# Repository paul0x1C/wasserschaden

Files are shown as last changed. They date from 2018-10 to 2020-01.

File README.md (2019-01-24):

# wasserschaden
Project to control solenoid valves over mqtt, check each nodes status in a webpage and via Grafana. 
It allows you to set a location for each node that connects for the first time for easier maintenance.
Nodes equipped with a temperature sensor also send temperature information via mqtt.
To prevent two solenoid valves opening simultaniously, a house enters "locked state". Before opening a solenoid valve,
it checks the lockstate of its house and will only open if the house is in unlocked state.
We log every opening and closing of a valve in order to be able to generate a csv log file, to prove reliability.

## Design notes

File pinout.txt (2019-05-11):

D1 GPIO5: valve (HIGH == OPEN) (20K PULLDOWN)
D2 GIPO4: info LED (HIGH == ON)
D6 GIPO12: sense (green screw terminal) (330R PULLUP)
D7 GIPO13: one wire temperature sensor (4K7 PULLUP)

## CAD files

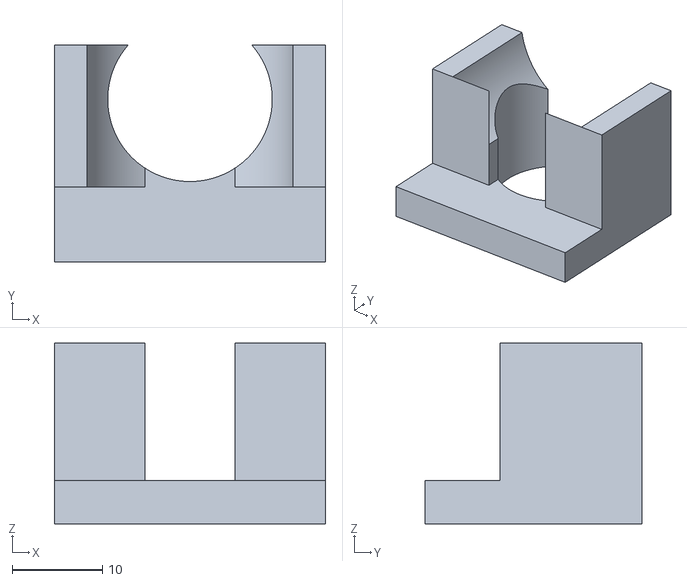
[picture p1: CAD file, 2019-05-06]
3D_models/valve.stl
30.0 x 24.0 x 20.0

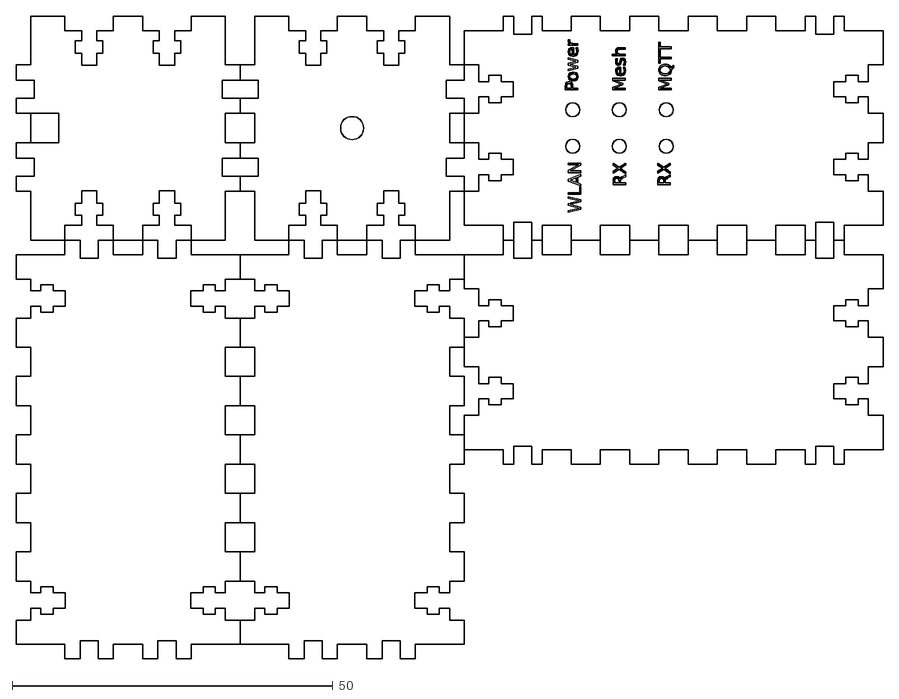
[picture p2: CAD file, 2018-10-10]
bridge_case/caseplans.dxf
135.1 x 100.2

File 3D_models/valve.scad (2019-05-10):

$fn = 300;

out_thread_h = 10.84;
out_thread_r = 10.33;
middle_h = 42.64;
middle_r = 9.1;
in_thrad_h = 10.21;
in_thread_r = 13.07;
overall_h = 65.88;
bent_middle_h = overall_h - (out_thread_h+middle_h+in_thrad_h);

rot_mid_h = 18.81;
rot_cube_h = 9.96;

module valve(){
     cylinder(r = out_thread_r, h=out_thread_h);
     translate([0,0,out_thread_h]){ //above outter thread
             translate([0,0,21.78]){//middle of the valve
                rotate([90,0,0]){
                  translate([0,0,-middle_r]){
                      cylinder(d=23.1,h=rot_mid_h);
                    translate([0,0,rot_mid_h]){
                        translate([0,0,rot_cube_h/2])cube([34,34,rot_cube_h], center=true);
                         cube([10,34,12], center = true);
                    }
                    }
              }
         }
         cylinder(r=middle_r, h=middle_h);
         translate([0,0,middle_h]){
             cylinder(r1=middle_r, r2=out_thread_r, h= bent_middle_h);
             translate([0,0,bent_middle_h])
                 cylinder(r=out_thread_r, h=out_thread_h);
         }
     }
}
translate([0,0,-out_thread_h])valve();
c_x = 30;
c_y = 24;
c_z = 20;
difference(){
    translate([-c_x/2,-c_y+6,0])
   color([1,0,0],0.8) cube([c_x,c_y,c_z]);
    translate([0,0,-out_thread_h])
    valve();
    
    
}

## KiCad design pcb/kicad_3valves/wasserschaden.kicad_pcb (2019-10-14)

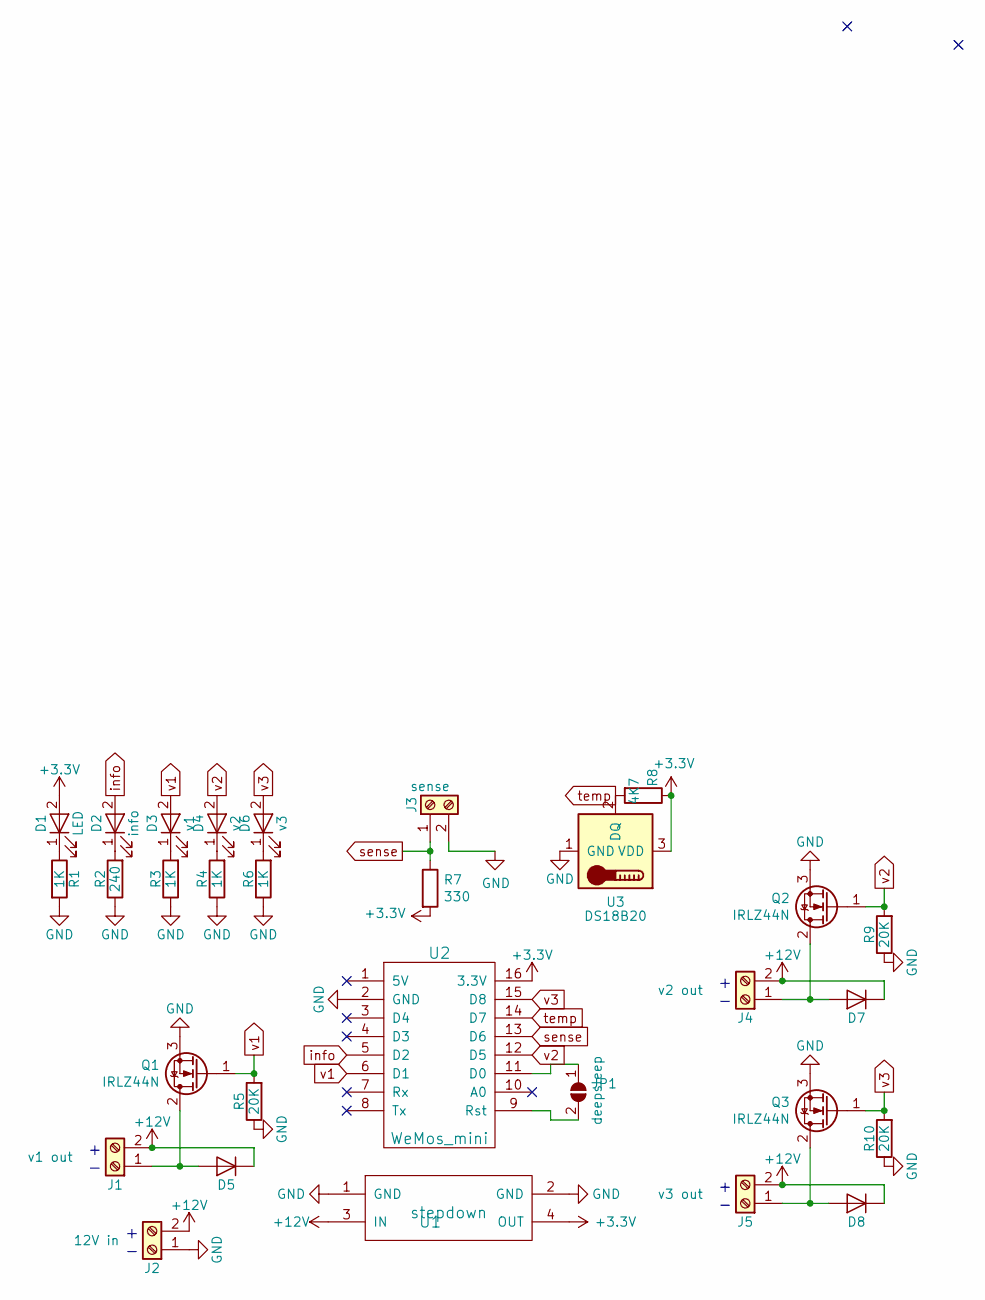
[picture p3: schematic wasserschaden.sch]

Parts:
D1: LED; LED_D3.0mm
D2: info; LED_D3.0mm
D3: v1; LED_D3.0mm
D4: v2; LED_D3.0mm
D5, D7, D8: D_SMA_Handsoldering
D6: v3; LED_D3.0mm
J1: v1 out; termina_2pin
J2: 12V in; termina_2pin
J3: sense; termina_2pin
J4: v2 out; termina_2pin
J5: v3 out; termina_2pin
JP1: deepsleep; jumper
Q1, Q2, Q3: IRLZ44N; TO-220-3_Vertical
R1, R3, R4, R6: 1K; R_0603_HandSoldering
R2: 240; R_0603_HandSoldering
R5, R9, R10: 20K; R_0603_HandSoldering
R7: 330; R_0603_HandSoldering
R8: 4K7; R_0603_HandSoldering
U1: stepdown
U2: WeMos_mini; wemos
U3: DS18B20; temperature_sensor

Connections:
+3V3: D1.2 (A), R7.2, R8.1, U1.4 (OUT), U2.16 (3.3V), U3.3 (VDD)
+12V: D5.1 (K), D7.1 (K), D8.1 (K), J1.2, J2.2, J4.2, J5.2, U1.3 (IN)
GND: J2.1, J3.2, Q1.3 (S), Q2.3 (S), Q3.3 (S), R1.2, R2.1, R3.1, R4.1, R5.1, R6.1, R9.1, R10.1, U1.1 (GND), U1.2 (GND), U2.2 (GND), U3.1 (GND)
unnamed: D1.1 (K), R1.1
unnamed: D2.1 (K), R2.2
unnamed: D3.1 (K), R3.2
unnamed: D4.1 (K), R4.2
unnamed: D5.2 (A), J1.1, Q1.2 (D)
unnamed: D6.1 (K), R6.2
unnamed: D7.2 (A), J4.1, Q2.2 (D)
unnamed: D8.2 (A), J5.1, Q3.2 (D)
unnamed: JP1.1 (A), U2.11 (D0)
unnamed: JP1.2 (B), U2.9 (Rst)
info: D2.2 (A), U2.5 (D2)
sense: J3.1, R7.1, U2.13 (D6)
temp: R8.2, U2.14 (D7), U3.2 (DQ)
v1: D3.2 (A), Q1.1 (G), R5.2, U2.6 (D1)
v2: D4.2 (A), Q2.1 (G), R9.2, U2.12 (D5)
v3: D6.2 (A), Q3.1 (G), R10.2, U2.15 (D8)

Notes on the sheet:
+ -

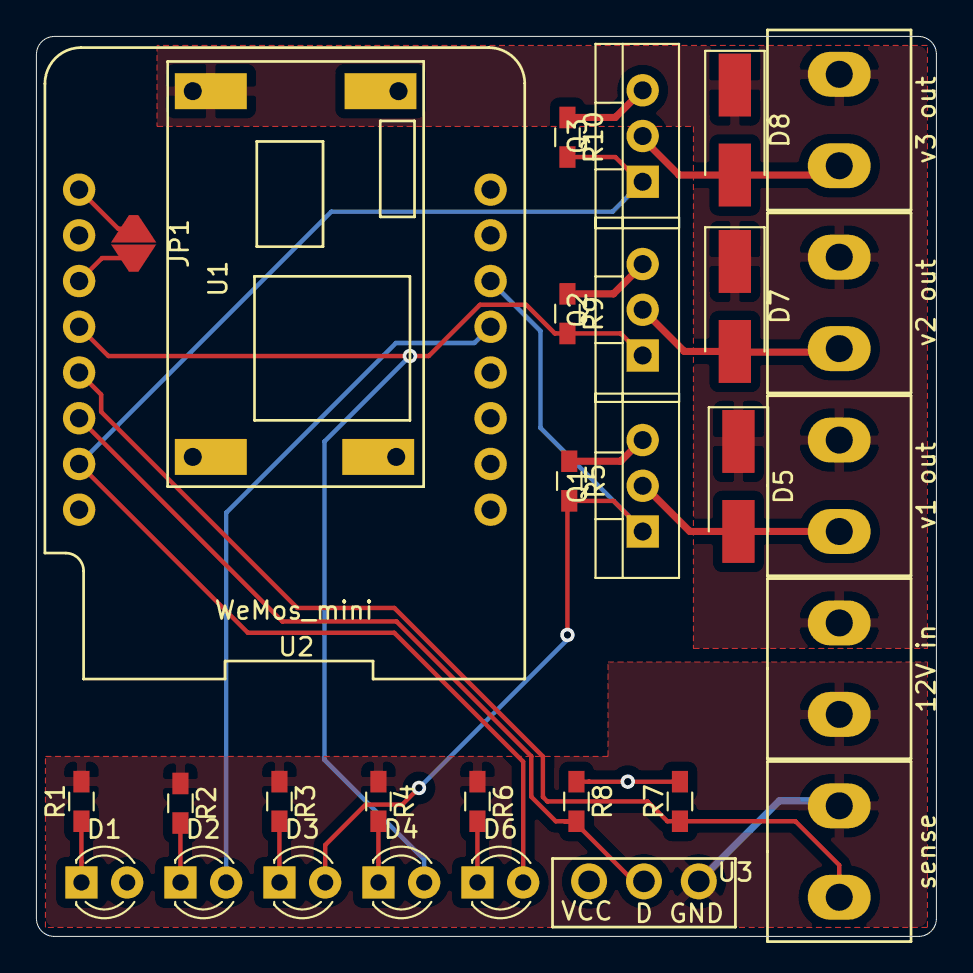
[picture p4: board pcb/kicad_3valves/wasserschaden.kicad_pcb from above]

Board: 2 copper layers, 50.0 x 50.0 mm, 30 parts (0 on the bottom side), 19 nets.

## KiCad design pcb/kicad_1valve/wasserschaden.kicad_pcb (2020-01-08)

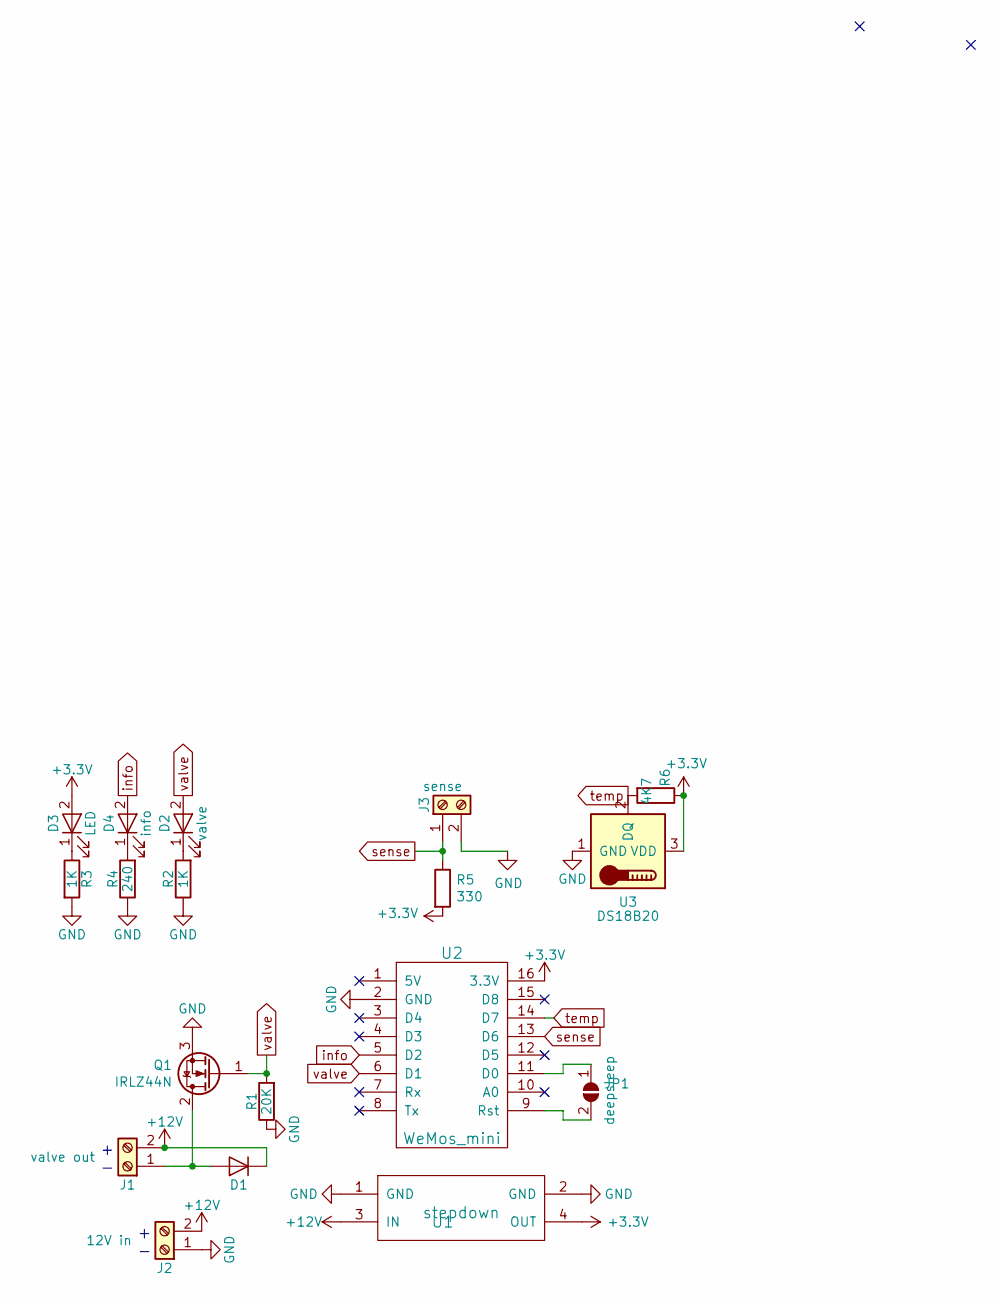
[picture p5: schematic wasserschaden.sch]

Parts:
D1: D_SMA_Handsoldering
D2: valve; LED_D3.0mm
D3: LED; LED_D3.0mm
D4: info; LED_D3.0mm
J1: valve out; termina_2pin
J2: 12V in; termina_2pin
J3: sense; termina_2pin
JP1: deepsleep; jumper
Q1: IRLZ44N; TO-220-3_Vertical
R1: 20K; R_0603_HandSoldering
R2, R3: 1K; R_0603_HandSoldering
R4: 240; R_0603_HandSoldering
R5: 330; R_0603_HandSoldering
R6: 4K7; R_0603_HandSoldering
U1: stepdown
U2: WeMos_mini; wemos
U3: DS18B20; temperature_sensor

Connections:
+3V3: D3.2 (A), R5.2, R6.1, U1.4 (OUT), U2.16 (3.3V), U3.3 (VDD)
+12V: D1.1 (K), J1.2, J2.2, U1.3 (IN)
GND: J2.1, J3.2, Q1.3 (S), R1.1, R2.1, R3.2, R4.1, U1.1 (GND), U1.2 (GND), U2.2 (GND), U3.1 (GND); also elsewhere on the board
unnamed 3: D1.2 (A), J1.1, Q1.2 (D); also elsewhere on the board
unnamed: D2.1 (K), R2.2
unnamed: D3.1 (K), R3.1
unnamed: D4.1 (K), R4.2
unnamed: JP1.1 (A), U2.11 (D0)
unnamed: JP1.2 (B), U2.9 (Rst)
info: D4.2 (A), U2.5 (D2)
sense: J3.1, R5.1, U2.13 (D6)
temp: R6.2, U2.14 (D7), U3.2 (DQ)
valve: D2.2 (A), Q1.1 (G), R1.2, U2.6 (D1); also elsewhere on the board

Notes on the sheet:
+ -

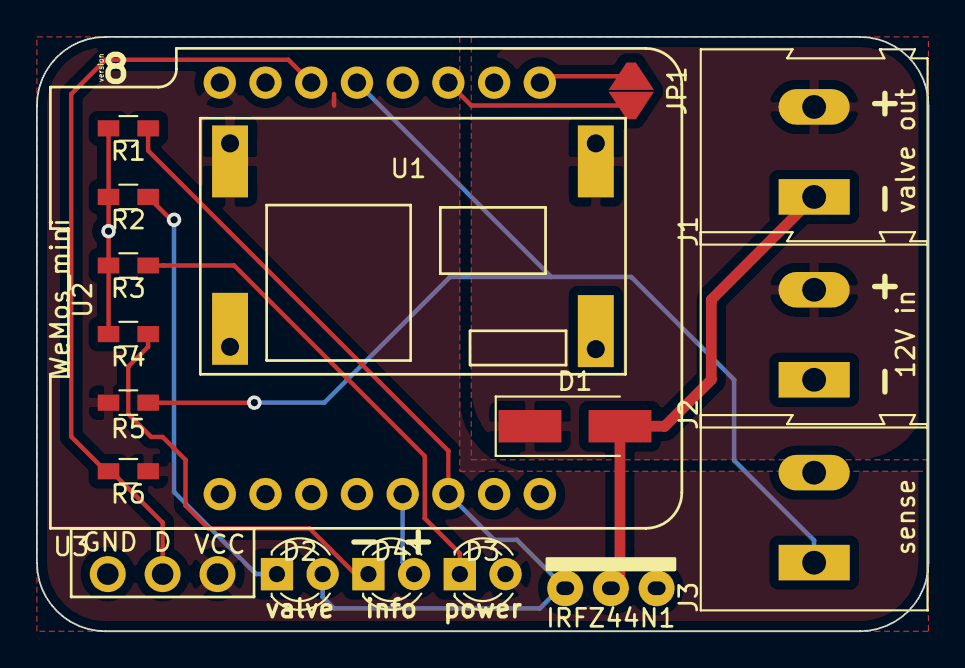
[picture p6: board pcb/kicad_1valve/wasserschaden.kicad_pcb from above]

Board: 2 copper layers, 49.5 x 33.0 mm, 18 parts (0 on the bottom side), 13 nets.

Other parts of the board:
IRFZ44N1: irlz44n_vertical

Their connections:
GND: IRFZ44N1.1; also elsewhere on the board
unnamed 3: IRFZ44N1.3; also elsewhere on the board
valve: IRFZ44N1.2; also elsewhere on the board

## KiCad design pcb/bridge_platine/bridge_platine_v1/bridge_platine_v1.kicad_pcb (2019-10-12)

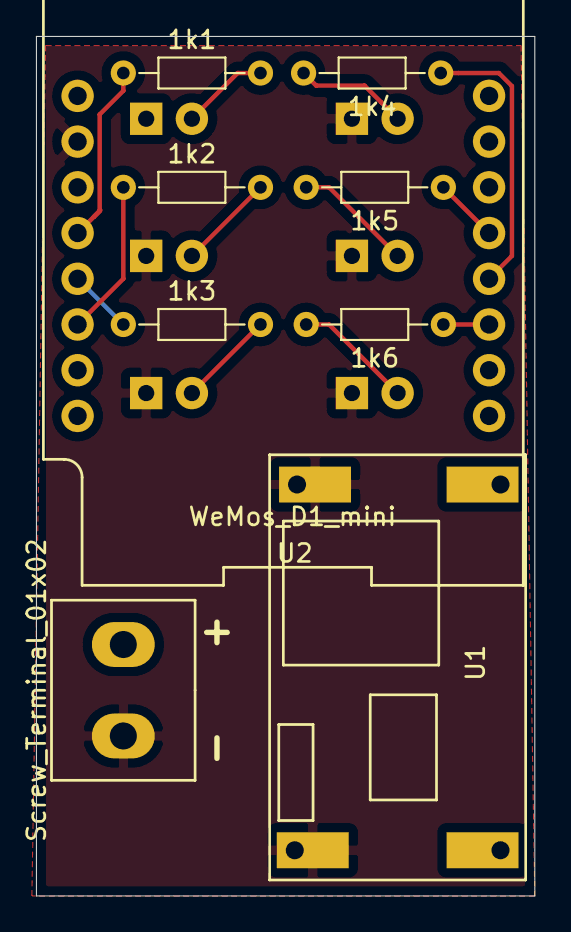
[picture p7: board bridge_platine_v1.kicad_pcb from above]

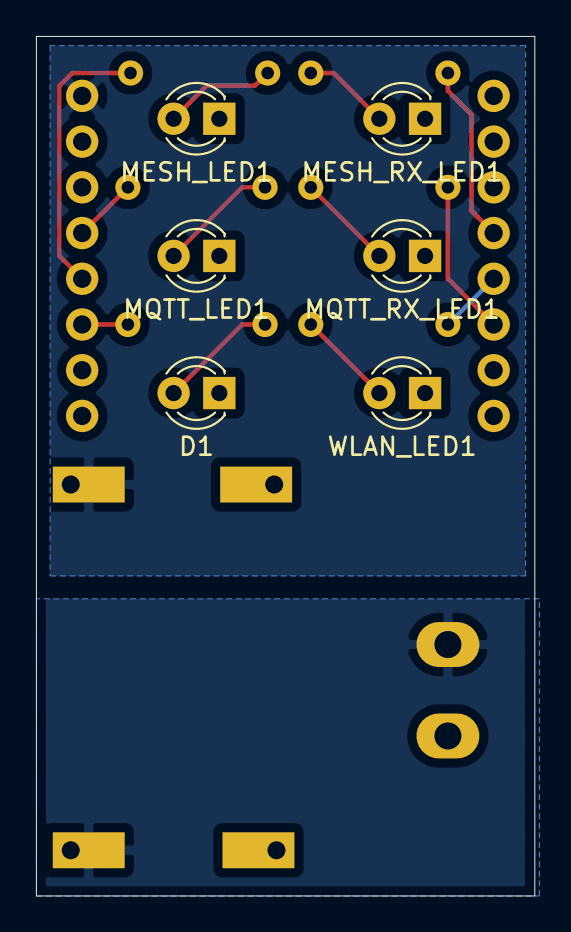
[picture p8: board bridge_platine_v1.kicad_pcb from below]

Board: 2 copper layers, 27.7 x 47.8 mm, 15 parts (6 on the bottom side), 15 nets.

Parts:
1k1, 1k2, 1k3, 1k4, 1k5, 1k6: R; R_Axial_DIN0204_L3.6mm_D1.6mm_P7.62mm_Horizontal
D1: POWER_LED; LED_D3.0mm
J1: Screw_Terminal_01x02; termina_2pin
MESH_LED1: LED; LED_D3.0mm
MESH_RX_LED1: LED; LED_D3.0mm
MQTT_LED1: LED; LED_D3.0mm
MQTT_RX_LED1: LED; LED_D3.0mm
U1: stepdown-wasserschaden-cache-2018-10-17-20-35-24; stepdown
U2: WeMos_D1_mini; wemos
WLAN_LED1: LED; LED_D3.0mm

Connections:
+3V3: U1.4, U2.8
GND: D1.1, J1.2, MESH_LED1.1, MQTT_LED1.1, MQTT_RX_LED1.1, U1.1, U1.2, U2.10, WLAN_LED1.1
unnamed: 1k1.1, U2.12
unnamed: 1k1.2, MESH_RX_LED1.2
unnamed: 1k2.1, U2.14
unnamed: 1k2.2, MQTT_RX_LED1.2
unnamed: 1k3.1, U2.13
unnamed: 1k3.2, WLAN_LED1.2
unnamed: 1k4.1, U2.4
unnamed: 1k4.2, MESH_LED1.2
unnamed: 1k5.1, U2.5
unnamed: 1k5.2, MQTT_LED1.2
unnamed: 1k6.1, U2.3
unnamed: 1k6.2, D1.2
unnamed: J1.1, U1.3

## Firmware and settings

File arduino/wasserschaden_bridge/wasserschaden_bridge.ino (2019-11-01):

#include <Arduino.h>
#include <painlessMesh.h>
#include <PubSubClient.h>
#include <WiFiClient.h>
#include "settings.cpp" //contains passwords

#define POWER_LED D0
#define WLAN_LED D2
#define MESH_LED D5
#define MQTT_LED D6
#define MQTT_RX_LED D1
#define MESH_RX_LED D3

#define   MESH_PORT       5555
#define HOSTNAME "MQTT_Bridge"

int leds[6] = {POWER_LED, WLAN_LED, MESH_LED, MESH_RX_LED, MQTT_LED, MQTT_RX_LED,};

// Prototypes
void receivedCallback(uint32_t from, String msg );
void mqttCallback(char* topic, byte* payload, unsigned int length);
void mqttConnect();
void mqtt_led_off();
void mesh_led_off();

char* message_buff;

String msg_ping = "ping";
String msg_welcome = "welcome";

const String from_bridge = String(MQTT_TOPIC)+"/from/bridge";

unsigned long last_msg;

int open_nodes = 0;
unsigned long last_open_msg;

IPAddress getlocalIP();

IPAddress no_ip(0, 0, 0, 0);
IPAddress myIP(0, 0, 0, 0);
IPAddress mqttBroker(6, 6, 6, 1);

painlessMesh  mesh;
WiFiClient wifiClient;
PubSubClient mqttClient(mqttBroker, 1883, mqttCallback, wifiClient);


Scheduler userScheduler;
Task reconnect(1000, TASK_FOREVER, &mqttConnect);
Task mqtt_blink(50, 1, &mqtt_led_off);
Task mesh_blink(50, 1, &mesh_led_off);

void setup() {
  ESP.wdtEnable(5000);
  pinMode(POWER_LED, OUTPUT);
  pinMode(WLAN_LED, OUTPUT);
  pinMode(MESH_LED, OUTPUT);
  pinMode(MQTT_LED, OUTPUT);
  pinMode(MQTT_RX_LED, OUTPUT);
  pinMode(MESH_RX_LED, OUTPUT);
  for(int i = 0; i < 6; i++){
    digitalWrite(leds[i], HIGH);
    delay(100);
    digitalWrite(leds[i], LOW);
  }
  last_msg = millis();
  Serial.begin(115200);
  digitalWrite(POWER_LED, HIGH);
  mesh.setRoot();
  mesh.setDebugMsgTypes( ERROR | STARTUP | CONNECTION );

  mesh.init( MESH_PREFIX, MESH_PASSWORD, MESH_PORT, WIFI_AP_STA, 4);
  mesh.onReceive(&receivedCallback);

  mesh.onNewConnection([](const uint32_t nodeId) {
    digitalWrite(MESH_LED, HIGH);
    if (nodeId != 0) {
      String topic = String(MQTT_TOPIC)+"/from/" + String(nodeId);
      mqttClient.publish((topic.c_str()), "connected");
      Serial.printf("New Connection \n", nodeId);
    }
  });

  mesh.onDroppedConnection([](const uint32_t nodeId) {
    if (nodeId != 0) {
      String topic = String(MQTT_TOPIC)+"/from/" + String(nodeId);
      mqttClient.publish(topic.c_str(), "dropped");
      Serial.printf("Dropped Connection %u\n", nodeId);
    }
    if (mesh.subConnectionJson().length() < 3) {
      digitalWrite(MESH_LED, LOW);
    }
  });

  mesh.stationManual(STATION_SSID, STATION_PASSWORD);
  mesh.setHostname(HOSTNAME);

  userScheduler.addTask(mesh_blink);
  userScheduler.addTask(mqtt_blink);
  userScheduler.addTask(reconnect);
}

void mqttConnect() {
  if (mqttClient.connect(String("pmC_"+String(MQTT_TOPIC)).c_str())) {
    digitalWrite(MQTT_LED, HIGH);
    Serial.println("connected to mqtt");
    mqttClient.publish(from_bridge.c_str(), "Ready!");
    mqttClient.subscribe(String(String(MQTT_TOPIC)+"/to/#").c_str(), 0);
    reconnect.disable();
  } else {
    digitalWrite(MQTT_LED, LOW);
  }
}

void mqtt_led_off() {
  if (mqtt_blink.isLastIteration()) {
    digitalWrite(MQTT_RX_LED, LOW);
    mqtt_blink.disable();
    mqtt_blink.setIterations(2);
  }
}

void mesh_led_off() {
  if (mesh_blink.isLastIteration()) {
    digitalWrite(MESH_RX_LED, LOW);
    mesh_blink.disable();
    mesh_blink.setIterations(2);
  }
}

void loop() {
  if(millis() < last_msg){ //reset last_msg when millis overflows every ~50 days
    last_msg = millis();
  }
  else if(millis() - last_msg > 1800000) { // half an hour
    ESP.reset(); //reset the esp when the last mqtt message was received to long ago
  }
  mesh.update();
  mqttClient.loop();

  if (myIP != getlocalIP()) {
    analogWrite(WLAN_LED, 200);
    myIP = getlocalIP();
    Serial.println("My IP is " + myIP.toString());
    mqttConnect();
  }
  if (myIP == no_ip) {
    digitalWrite(WLAN_LED, LOW);
  } else {
    analogWrite(WLAN_LED, 200);
  }
  if (!mqttClient.connected() and !reconnect.isEnabled()) {
    reconnect.enable();
    Serial.println("enabled reconnect task");
  }
  userScheduler.execute();
}

void receivedCallback(uint32_t from, String msg ) {
  digitalWrite(MESH_RX_LED, HIGH);
  Serial.printf("bridge: Received from %u msg=%s\n", from, msg.c_str());
  String topic = String(MQTT_TOPIC)+"/from/" + String(from);
  mqttClient.publish(topic.c_str(), msg.c_str());
  mesh_blink.enable();
  if(msg == "online"){
    mesh.sendSingle(from, msg_welcome);
  }else if(msg == "closing")
  {
    if(open_nodes > 0)
    {
      open_nodes -= 1;
    }
  }
}

void mqttCallback(char* topic, uint8_t* payload, unsigned int length) {
  last_msg = millis();
  digitalWrite(MQTT_RX_LED, HIGH);
  
  char* cleanPayload = (char*)malloc(length+1);
  payload[length] = '\0';
  memcpy(cleanPayload, payload, length+1);
  String msg = String(cleanPayload);
  free(cleanPayload);

  String targetStr = String(topic).substring(String(MQTT_TOPIC).length()+4);
  if (targetStr == "bridge")
  {
    if (msg == "getNodes")
    {
      Serial.println( mesh.subConnectionJson().c_str());
      mqttClient.publish(from_bridge.c_str(), mesh.subConnectionJson().c_str());
    }else if(msg == "ping")
    {
      Serial.println("ping recived, sending pong");
      mqttClient.publish(from_bridge.c_str(), "pong");
    }
  }
   else if(targetStr == "broadcast") 
  {
    if(msg != "open") // let's just don't broadcast open msgs
    {
      Serial.println("broadcasting to mesh: " + msg);
      mesh.sendBroadcast(msg);
    }else{
      String pubtopic = String(MQTT_TOPIC)+"/from/bridge";
      mqttClient.publish(pubtopic.c_str(), "rejected");
      Serial.println("rejected broadcast");
    }
  }
  else
  {
    uint32_t target = strtoul(targetStr.c_str(), NULL, 10);
    if (mesh.isConnected(target))
    {
      if (msg == "open")
      {
        if(millis() < last_open_msg){ // reset last_open_msg when millis overflows every ~50 days
            last_open_msg = millis();
        }
        else if(millis() - last_open_msg > 120000) // check if last open msg happened 2 minutes ago
        {
          open_nodes = 0;
        }
        if(open_nodes == 0)
        {
          last_open_msg = millis();
          open_nodes += 1;
          Serial.println("sending " + msg+ " to " + target);
          mesh.sendSingle(target, msg);
        }
        else // reject open command, since there might be more open nodes
        {
          String pubtopic = String(MQTT_TOPIC)+"/from/bridge";
          mqttClient.publish(pubtopic.c_str(), "rejected");
          Serial.println("rejected open command");
        }
      }
      else
      {
       mesh.sendSingle(target, msg);
       Serial.println("sending " + msg+ " to " + target);
      }
   }
   else
   {
    String pubtopic = String(MQTT_TOPIC)+"/from/" + targetStr;
    mqttClient.publish(pubtopic.c_str(), "offline");
   }
  }
  mqtt_blink.enable();
}

IPAddress getlocalIP() {
  return IPAddress(mesh.getStationIP());
}

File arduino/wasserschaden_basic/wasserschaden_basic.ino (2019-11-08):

#include "painlessMesh.h"

#include <OneWire.h>
#include <DallasTemperature.h>

#include "settings.cpp" //contains definition of MESH_PREFIX and MESH_PASSWORD

const int flushTime = 150000;
const int valve_pin = D1;
const int status_pin = D2;
const int sense_pin = D6; // version >=8: D7; else: D3
const int temperature_pin = D7;
const int opened_value = HIGH;
const int closed_value = LOW;

//timeouts for actions when no bridge is found
const int last_msg_timeout = 60000;
const int attempt_timeout = 5000;
boolean con_resent = false;
int bridge_ping_attempts = 0;
long last_bridge_msg = millis();
long last_bridge_attempt = millis();

long last_sense_msg = millis();
boolean sense_state = false;
boolean last_sent_sense_state = false;

String msg_open = "opening";
String msg_close = "closing";
String msg_connected = "online";
String msg_ping = "pong";
String msg_sense = "sense";

boolean blink_state = false;
boolean first_time_adjust = true;
boolean is_open = false;
boolean from_bridge;

uint32_t bridge = 0;

long running_since;

OneWire oneWire(temperature_pin);
DallasTemperature sensors(&oneWire);

Scheduler userScheduler;
painlessMesh  mesh;

// User stub
void sendMessage() ; // Prototype so PlatformIO doesn't complain
void valve();
void blink();
Task closeValveTask(flushTime, 2, &valve);
Task pingBlink(100, 6, &blink);

// Needed for painless library
void receivedCallback( uint32_t from, String &msg ) {
  from_bridge = true;
  Serial.printf("startHere: Received from %u msg=%s\n", from, msg.c_str());
  if(msg == "open"){
    bridge = from;
    Serial.println("Received open message");
    open_valve();
  }else if(msg == "close"){
    bridge = from;
    Serial.println("Received close message");
    close_valve();
  }else if(msg == "ping"){
    bridge = from;
    mesh.sendSingle(from, msg_ping);
    Serial.println("ping");
    pingBlink.enable();
  }else if(msg == "temp"){
    bridge = from;
    sensors.requestTemperatures();
    mesh.sendSingle(from, "t:" + String(sensors.getTempCByIndex(0)));
  }else if(msg == "sense"){
    bridge = from;
    mesh.sendSingle(from, "s:" + String(sense_water()));
  }else if(msg == "state"){
    bridge = from;
    mesh.sendSingle(from, "v:" + String(is_open));
  }else if(msg == "welcome"){
    bridge = from;
  }else{
    from_bridge = false;
  }
  if (from_bridge){
    last_bridge_msg = millis();
  }
}
void blink(){
  if (pingBlink.isLastIteration()){
    digitalWrite(status_pin, LOW);
    blink_state = true;
    pingBlink.disable();
    pingBlink.setIterations(6);
  }else{
    blink_state = !blink_state;
    digitalWrite(status_pin, blink_state);
    Serial.println(blink_state);
  }
}


void nodeTimeAdjustedCallback(int32_t offset) {
    Serial.printf("Adjusted time %u. Offset = %d\n", mesh.getNodeTime(),offset);
    if(first_time_adjust){
      mesh.sendBroadcast(msg_connected);
      first_time_adjust = false;
    }
}

void valve(){
   if (closeValveTask.isLastIteration()){
    close_valve();
    closeValveTask.disable();
   }
}

void open_valve(){
  closeValveTask.setIterations(2);
  closeValveTask.enable();
  Serial.println("Opening valve");
  mesh.sendSingle(bridge, msg_open); 
  digitalWrite(valve_pin, opened_value);
  is_open = true;
}

void close_valve(){
  Serial.println("Closing valve");
  mesh.sendSingle(bridge, msg_close); 
  digitalWrite(valve_pin, closed_value);
  closeValveTask.disable();
  is_open = false;
}
void setup() {
  Serial.begin(115200);
  Serial.println("entering setup");
  close_valve();
  
  mesh.setDebugMsgTypes( ERROR | STARTUP | CONNECTION ); 
  
  mesh.init( MESH_PREFIX, MESH_PASSWORD, &userScheduler, 5555, WIFI_AP_STA, 4); //defined in extra file thats not on github
  mesh.setContainsRoot();
  mesh.onReceive(&receivedCallback);
  mesh.onNodeTimeAdjusted(&nodeTimeAdjustedCallback);

  sensors.begin();
  
  userScheduler.addTask( closeValveTask );
  userScheduler.addTask( pingBlink );
  pinMode(status_pin, OUTPUT);
  pinMode(valve_pin, OUTPUT);
  pinMode(sense_pin, INPUT);
  pingBlink.setIterations(2);
  pingBlink.enable();
  running_since = millis();
  Serial.println("setup finished");
}

boolean sense_water(){
  return !digitalRead(sense_pin);
}

void loop() {
  userScheduler.execute();
  mesh.update();
  
  if(sense_water()){
    if(is_open){
      close_valve();
    }
    sense_state = true;
    if(last_sense_msg > millis()){
      last_sense_msg = millis();
    }else if(millis() - last_sense_msg > 20000){
      last_sense_msg = millis();
      mesh.sendSingle(bridge, "s:" + String(sense_state));
    }
  }else{
    sense_state = false;
  }

  if (sense_state != last_sent_sense_state){
    if(millis() - last_sense_msg > 2000){
      mesh.sendSingle(bridge, "s:" + String(sense_state));
      last_sent_sense_state = sense_state;
      last_sense_msg = millis();
    }
  }
  
  if(last_bridge_msg > millis()){
    last_bridge_msg = millis();
  }else if(millis() - last_bridge_msg > last_msg_timeout){
    if(last_bridge_attempt > millis()){
      last_bridge_attempt = millis();
    }else if(millis() - last_bridge_attempt > attempt_timeout){
      if (bridge_ping_attempts < 3) {
        Serial.println("resending connected msg");
        mesh.sendBroadcast(msg_connected);
        bridge_ping_attempts++;
      }
      last_bridge_attempt = millis();
    }
  }else{
    bridge_ping_attempts = 0;
  }
  if (bridge_ping_attempts >= 3){
     ESP.reset();
  }
}

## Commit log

2018-08-26 splited loop.py in timer_loop.py and mqtt_loop.py; fixed automatic mqtt reconnect
2018-08-26 added autorefresh on/off switch
2018-08-26 removed old files
    [log.csv]
2018-10-01 added status leds
2018-10-01 added caseplans
    [caseplans.dxf]
2018-10-05 implemented status leds
2018-10-10 Revert "custom mqtt topic"
    This reverts commit 6651eda04687c469d4528e4c1a76eaf6a2c9868e.
    [wasserschaden_bridge.ino]
2018-10-10 Revert "string fuu"
    This reverts commit 82bc943778d458de0eda92c456a078fc5ff517e1.
    [wasserschaden_bridge.ino]
2018-10-17 added kicad files
    [wasserschaden-2018-10-17-20-35-24.sch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]
2018-10-17 clear queue button
2018-10-22 use for new nodes button
2018-10-24 added deepsleep jumper to schematic &cleanup
    [_saved_wasserschaden.sch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]
2018-10-24 moved caseplans to own folder
    [caseplans.dxf]
2018-11-08 moved node state change to timer_loop, added workaround for relationship bug
2018-11-08 added watchdog, fixed bug with custom bridge topics
    [wasserschaden_bridge.ino]
2018-11-09 added jumper to pcb
    [wasserschaden.kicad_pcb, wasserschaden.sch]
2018-11-10 added sense jumper to schematic
    [wasserschaden.sch]
2018-11-12 cleaned up kicad dir
    [_saved_wasserschaden.sch]
2018-11-12 added sense input
    [_saved_wasserschaden.sch, noname.kicad_pcb, wasserschaden.sch]
2018-11-12 major pcb rearangement
    [wasserschaden.kicad_pcb]
2018-11-13 added button selection for priority levels
2018-11-13 pcb redesigen
    [wasserschaden.kicad_pcb]
2018-11-28 enabled watchdog, changed flushtime, reboot if bridge is not found
    [wasserschaden_basic.ino, wasserschaden_bridge.ino]
2018-12-01 fixed timer_loop failing when last_flush is not set
2018-12-05 added led test on boot
2018-12-06 only process que if qateway is connected
2018-12-06 added temperature sensor
    [wasserschaden.kicad_pcb, wasserschaden.sch]
2018-12-08 added R values, improved stepdown footprint, rerouted resistors
    [wasserschaden.kicad_pcb, wasserschaden.sch]
2019-01-10 added temperature and water sense, updated communication
2019-01-13 nicer silkscreen
    [wasserschaden-B.Cu.gbr, wasserschaden-B.Mask.gbr, wasserschaden-B.SilkS.gbr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]
2019-01-13 updated communication, added temperature sensror, set root node
2019-01-31 run one wire on the right pin ^^
2019-01-31 added 12V zone, made screw terminals interlockable
    [wasserschaden-B.Cu.gbr, wasserschaden-B.Mask.gbr, wasserschaden-B.SilkS.gbr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]
2019-02-08 first smd version
    [wasserschaden_smd.kicad_pcb, wasserschaden_smd.sch]
2019-02-08 v4 export
    [wasserschaden-B.Cu.gbr, wasserschaden-B.Mask.gbr, wasserschaden-B.SilkS.gbr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]
2019-02-14 small rerouting
    [wasserschaden_smd.kicad_pcb]
2019-02-27 prevent temperature request spamming
2019-04-09 pcb v7
    [wasserschaden_smd-B.Cu.gbr, wasserschaden_smd-B.Mask.gbr, wasserschaden_smd-B.Paste.gbr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]
2019-04-09 added temperature sensor reset option
2019-04-16 fixed traces near pads
    [wasserschaden_smd-B.Cu.gbr, wasserschaden_smd-B.Mask.gbr, wasserschaden_smd-B.Paste.gbr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]
2019-05-06 added 3d design for valves on HT pipe
    [valve.scad, valve.stl]
2019-05-10 added colors
    [valve.scad]
2019-05-11 moved sense pin from D3 to D6 since D3 must be HIGH on boot
    [wasserschaden.sch]
2019-05-11 copied v7
    [version7.kicad_pcb]
2019-05-11 fixed D3 in current pcb
    [wasserschaden_smd.kicad_pcb]
2019-05-11 cleaned up old files and replaced main pcb with smd version
    [version4.kicad_pcb]
2019-07-05 reset bridge after 30m without a mqtt msg
    [wasserschaden_bridge.ino]
2019-07-16 moved kicad files
    [noname.kicad_pcb, version4.kicad_pcb, version7.kicad_pcb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]
2019-07-16 make use of net labels more often
    [noname.kicad_pcb, wasserschaden_tht.sch]
2019-07-17 first routing atempt for 3 valve board
    [wasserschaden.kicad_pcb, wasserschaden.sch]
2019-07-17 fancy routing for 3 valve board
    [wasserschaden.kicad_pcb, wasserschaden.sch]
2019-08-01 set has_temerature_sensor to false when nodes don't have a sensor
2019-08-06 attempts instead of attemps… oof
2019-08-12 flush now button
2019-08-12 add flush now button
2019-08-12 3 valve pcb
    [wasserschaden.kicad_pcb]
2019-09-23 fix connecton_state timer not resetting
2019-09-28 ignore gerber, drill and zip files
2019-09-28 round corners
    [wasserschaden.kicad_pcb]
2019-09-29 version 8
    [version8.kicad_pcb]
2019-09-29 fixed terminal spacing
    [wasserschaden.kicad_pcb]
2019-09-29 reboot when bridge is unreachable for to long
    [wasserschaden_basic.ino, wasserschaden_bridge.ino]
2019-09-29 PCB for bridge
    [bridge_platine_v1.kicad_pcb, bridge_platine_v1.sch]
2019-10-03 added missing track
    [bridge_platine_v1.kicad_pcb]
2019-10-12 store timestamps with milliseconds
2019-10-14 use propper symbol and footprint for irlz44n
    [version8.kicad_pcb, wasserschaden.kicad_pcb, wasserschaden.sch]
2019-10-28 adapted LED holes for bridge PCB v1
2019-11-01 fix ping, automaticlly send sense msg when detecting water
    [wasserschaden_basic.ino]
2019-11-08 close valve when detecting water
2019-11-13 add access control to buttons, more infos for nodes
2019-11-13 automaticly add buttons for objects mentoined in alerts
2019-12-09 add more buttons and clean_alerts command
2020-01-08 moved pcbs to own folder
    [bridge_platine_v1.kicad_pcb, bridge_platine_v1.sch, version4.kicad_pcb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]
